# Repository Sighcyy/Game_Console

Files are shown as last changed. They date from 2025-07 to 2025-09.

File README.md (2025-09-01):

# Game_Console

This project is a custom-built, minimalist handheld game console inspired by the iconic Game Boy Color. Designed from the ground up, it features a compact PCB, a high-quality 3.5” LED display, and a rechargeable lithium-ion battery system—all housed in a sleek, ergonomically designed enclosure.

# Project Overview
Total Time Spent: ~18 hours

After completing two previous electronics projects focused primarily on PCB design and signal routing, I wanted to expand my skills by creating a fully portable device with a display and physical controls. The goal was to build a retro-style gaming device capable of running classic games like Pokémon, Tetris, and Super Mario while embracing a clean and minimalist aesthetic.

Key design decisions included using the Raspberry Pi Zero 2 WH as the main processing unit due to its compact size and emulation capabilities, and choosing an LED screen without integrated audio to simplify the design. The power system was upgraded to a rechargeable lithium-ion battery paired with a boost converter, allowing efficient voltage regulation and easy wiring underneath the Pi board.

Technical Highlights
Compact PCB Layout: Designed under 100x100 mm for cost-effective manufacturing and compactness.

Component Integration: Custom 3D CAD modeling to accommodate the battery, boost converter, microcontroller, and display, ensuring precise fit within a custom enclosure.

Minimalist Design: Removed unnecessary components such as the rotary encoder to maintain a streamlined, user-friendly form factor.

Firmware & Emulation: Leveraged RetroPie, a community-supported emulator platform that supports extensive button configuration, simplifying software setup.

Custom Soldering Documentation: Created unique schematic visualizations to document the process of soldering wires to the underside of the Raspberry Pi Zero 2 WH for a clean internal layout.



# Project Goal
The goal of this project is to create a fully functional, portable retro gaming console that captures the nostalgic feel of classic handheld devices like the Game Boy Color. This involves designing a compact, cost-effective PCB layout under 100x100 mm that integrates the Raspberry Pi Zero 2 WH, a 3.5” LED display, power components, and physical controls. A minimalist yet ergonomic enclosure is developed through precise 3D CAD modeling to securely house all parts while maintaining a sleek form factor. The project also aims to implement a reliable rechargeable power system using a lithium-ion battery and boost converter for consistent voltage delivery. By leveraging open-source emulation software like RetroPie, the console supports a wide range of classic games with easily configurable controls, simplifying the firmware side of the build. Finally, clear documentation of the hardware assembly, including custom wiring and soldering techniques, ensures the design is reproducible and ready for future enhancements.

# BOM


# CAD




# PCB and Shcematic and Wiring





# Firmware



https://retropie.org.uk/

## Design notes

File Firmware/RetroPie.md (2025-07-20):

For this section of the game console I have decided to use a pre-made OS called Retro Pie, which I can download into a MicroSD card and configured controls and insert ROM games in order to actually be able to play games. Below I have included the link to the time:

https://retropie.org.uk/

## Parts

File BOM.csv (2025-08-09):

Name | Vendor | Cost | Link
Touch Display | Waveshare | $24.99 | https://www.waveshare.com/product/raspberry-pi/3.5inch-rpi-lcd-c.htm
M3 Screw Assortment Kit | Ali-Express | $8.66 | https://www.aliexpress.us/item/3256803907721123.html?mp=1
HDMI Male to Female Flat Cable | Amazon | $7.59 | https://www.amazon.com/gp/product/B09F61FZWQ/ref=ox_sc_act_title_2?smid=A13KR3FLHKYL23&psc=1
2 pin Switches | Ali-Express | $1.15 | https://www.aliexpress.us/item/3256804784951471.html?mp=1
Heatsink | Ali-Express | $2.99 | https://www.aliexpress.us/item/3256807274777041.html?mp=1
On Off SWitch | Ali-Express | $4.59 | https://www.aliexpress.us/item/3256801856423528.html?mp=1
Raspberry Pi Zero W 2 with Headers | Micro Center | $17.99 | https://www.microcenter.com/product/683270/Raspberry_Pi_Zero_W_2_with_Headers
50 ft. 30AWG Silicone Cover Stranded-Core Wire | Micro Center | $4.99 | https://www.microcenter.com/product/471495/50_ft_30AWG_Silicone_Cover_Stranded-Core_Wire_-_Red
Lithium Ion Battery - 3.7v 2000mAh | Micro Center | $9.96 | https://www.microcenter.com/product/503621/Lithium_Ion_Battery_-_37v_2000mAh
MicroSD with Adapter | Micro Center | $4.99 | https://www.microcenter.com/product/658767/64GB_Ultra_microSDXC_Class_10_Flash_Memory_Card_with_Adapter
PowerBoost 1000 Charger | Micro Center | $19.99 | https://www.microcenter.com/product/474415/PowerBoost_1000_Charger_-_Rechargeable_5V_Lipo_USB_Boost_@_1A
Shipping Total | Waveshare | $15 | ________
Shipping Total | Amazon | $0 | ___________
Shipping and Additional Charges Total | Ali-Express | 11.89 | ____________-
Shipping Total | MicroCenter | $10 | __________
Total | All Places | $124.79 | ________-
Final Costs with Tax Estimation | All Places | $130 | ___

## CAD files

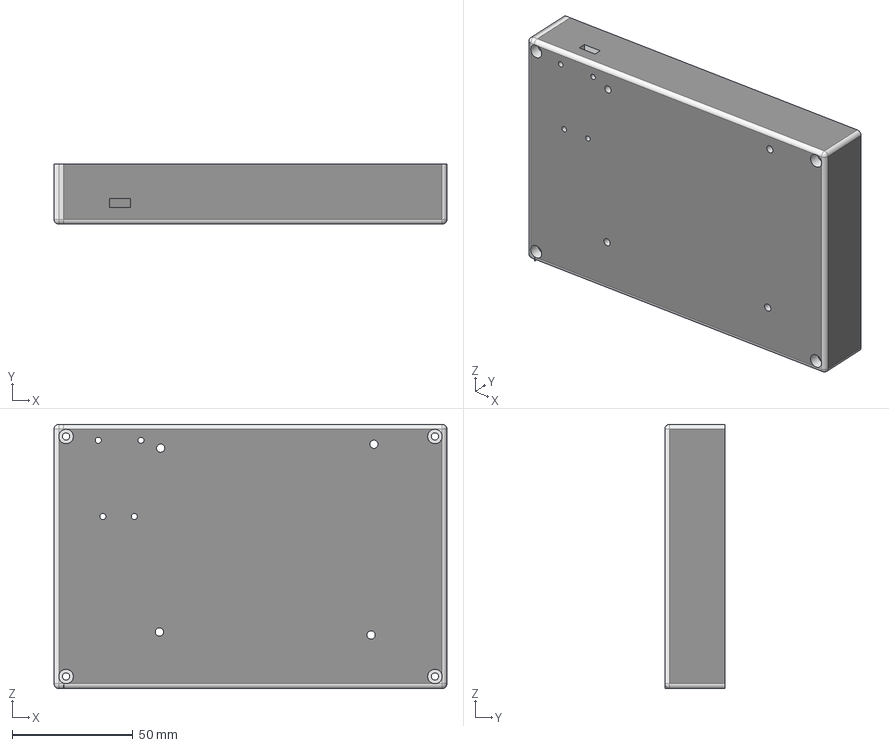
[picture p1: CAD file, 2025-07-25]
CAD/COC.stp
162.6 x 25.0 x 109.4 mm

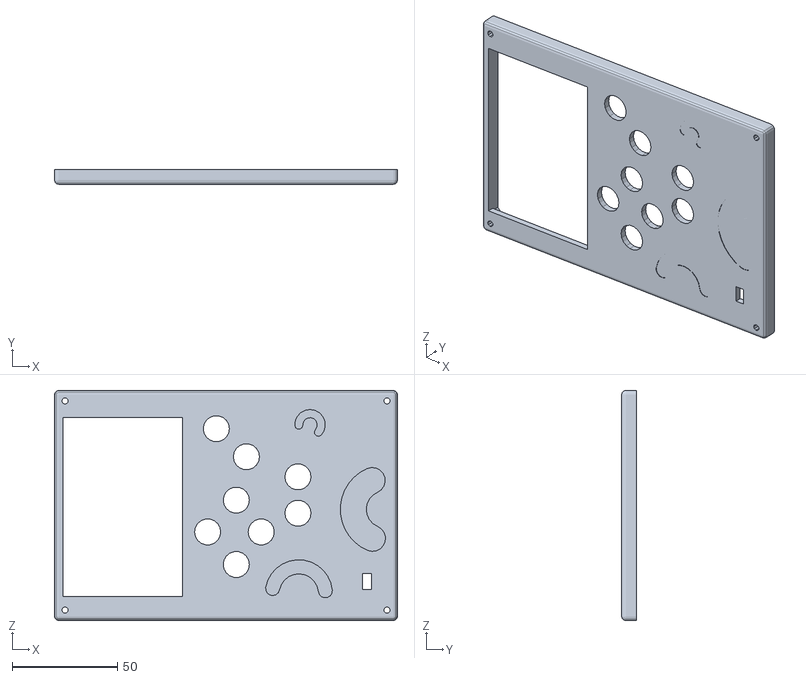
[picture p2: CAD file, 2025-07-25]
Production/POC.stl
162.9 x 7.00 x 109.3

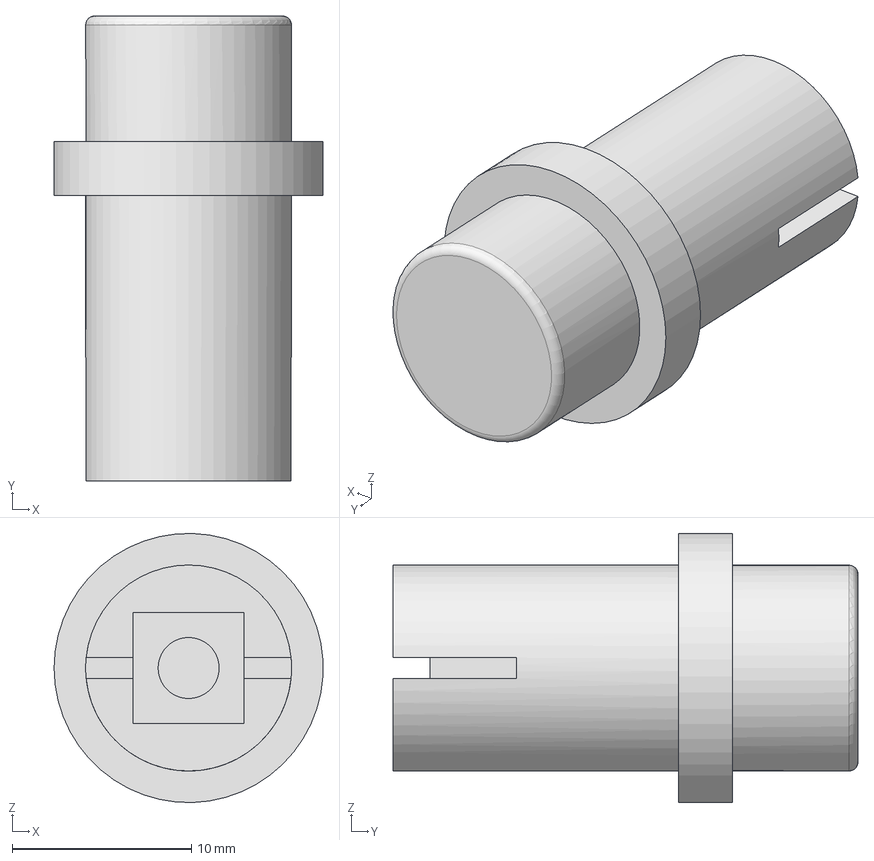
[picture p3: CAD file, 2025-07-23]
CAD/THEREALBUTTON.stp
15.0 x 25.9 x 15.0 mm

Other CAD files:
CAD/POC.stp
Production/COC.stl
Production/THEREALBUTTON.stl
CAD/COC.ipt
CAD/COC.stl
CAD/Fully_made_PCB.iam
CAD/POC.ipt
CAD/THEREALBUTTON.ipt

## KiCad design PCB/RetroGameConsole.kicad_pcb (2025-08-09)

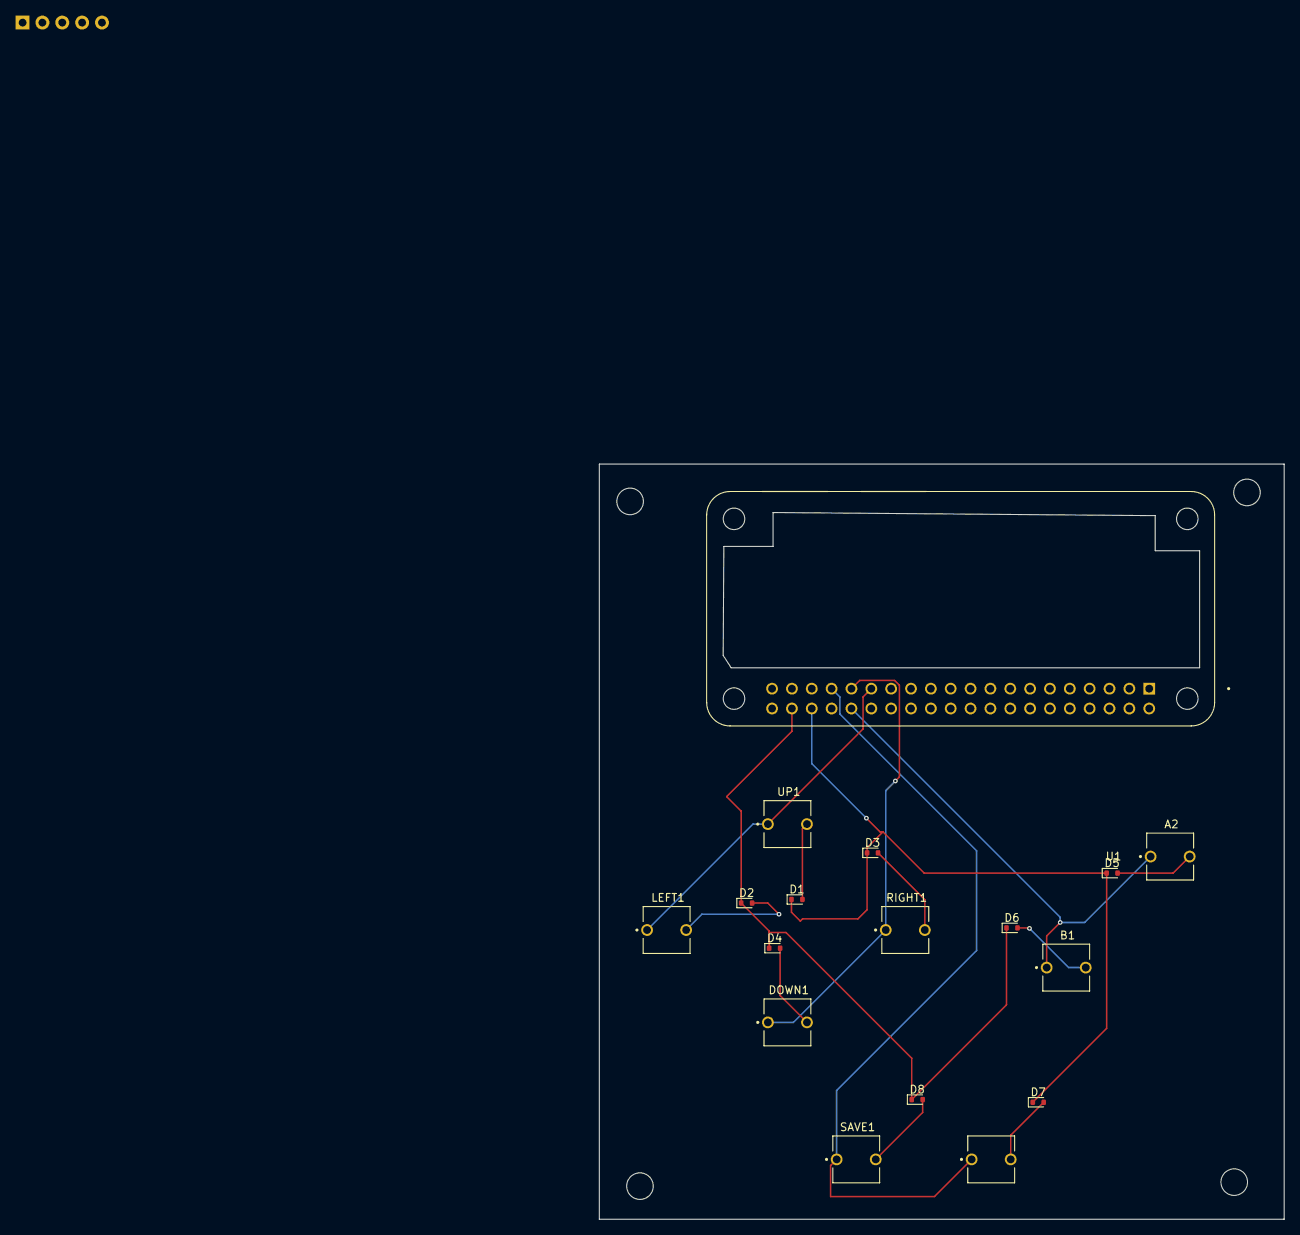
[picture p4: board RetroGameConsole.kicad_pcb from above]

Board: 2 copper layers, 87.6 x 96.6 mm, 18 parts (0 on the bottom side), 14 nets.

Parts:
A2: BUTT-2; SW_BUTT-2
B1: BUTT-2; SW_BUTT-2
D1, D2, D3, D4, D5, D6, D7, D8: 1N4148WT; D_SOD-523
DOWN1: BUTT-2; SW_BUTT-2
LEFT1: BUTT-2; SW_BUTT-2
RIGHT1: BUTT-2; SW_BUTT-2
SAVE1: BUTT-2; SW_BUTT-2
SELECT1: BUTT-2; SW_BUTT-2
U1: RASPBERRY_PI_ZERO_2_W; MODULE_RASPBERRY_PI_ZERO_2_W
U2: PAM8302AASCR; 1X05_ROUND_70
UP1: BUTT-2; SW_BUTT-2

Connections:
Column1: LEFT1.1, U1.29 (GPIO5), UP1.1
Column2: DOWN1.1, RIGHT1.1, U1.31 (GPIO6)
Column3: A2.1, B1.1, U1.32 (GPIO12)
Column4: SAVE1.1, SELECT1.1, U1.33 (GPIO13)
unnamed: D1.2 (A), UP1.2
unnamed: D2.2 (A), LEFT1.2
unnamed: D3.2 (A), RIGHT1.2
unnamed: D4.2 (A), DOWN1.2
unnamed: A2.2, D5.2 (A)
unnamed: B1.2, D6.2 (A)
unnamed: D7.2 (A), SELECT1.2
unnamed: D8.2 (A), SAVE1.2
Row1: D1.1 (K), D3.1 (K), D5.1 (K), D7.1 (K), U1.36 (GPIO16)
Row2: D2.1 (K), D4.1 (K), D6.1 (K), D8.1 (K), U1.38 (GPIO20)

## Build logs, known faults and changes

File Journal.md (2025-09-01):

# June 29th, 2025
Time: 2 hours

Today was a significant milestone in my personal electronics journey. After completing my second project—which was heavily focused on PCB design and signal routing—I realized there were areas I hadn’t explored yet, particularly portability, audio integration, and display hardware. With that in mind, I decided to begin my third project: designing and building a custom retro-style handheld game console. Inspired by the Game Boy Color and the nostalgia of games like Pokémon, Tetris, and Super Mario, I wanted to create something that captured that retro aesthetic but also pushed me into new technical territory. Unlike my previous work, this project would combine multiple disciplines: display interfacing, audio output, power management, and user input through physical controls.

Today’s focus was on planning and sourcing all the core components. I researched compact 3.5” displays compatible with SPI or parallel interfaces, small mono speakers with amplifier boards like the PAM8302, and a rechargeable Li-Po battery system using modules such as the PowerBoost 1000C. I also started considering how to route inputs from tactile buttons into the main processing board—likely a Raspberry Pi Zero 2 W for its compact form and emulation capabilities. With the parts identified, the next step is to begin the schematic design, where I’ll bring together power, video, audio, and controls into a single PCB. While I have ideas for future enhancements, like a unique case or custom OS interface, today was about laying the technical foundation.



# June 30th, 2025
Time : 3 hours

Today was all about refining the hardware planning process. I initially ran into a roadblock when I discovered that many of the footprints for the switches I intended to use were missing from the standard libraries. To solve this, I turned to SnapEDA to search for compatible footprints and cross-referenced them with GrabCAD to find accurate 3D models. This allowed me to visualize how each component would fit together, especially in relation to the microcontroller and 3.5” LED screen, helping me take precise measurements and maintain ergonomic spacing for the physical controls.

During this process, I made a key decision to switch my microcontroller to a Raspberry Pi Zero 2 WH. Its onboard Wi-Fi and processing power made it a better fit for a retro game console, especially for emulation tasks and future expandability. With most of the components selected and properly modeled, I sketched out a rough layout of the PCB, visualizing how everything—screen, buttons, speakers, power module—would come together on a single board. This early planning stage will help streamline the schematic and layout phase moving forward.

 


# July 1st, 2025
Time: 3 hours

Today didn’t go as smoothly as I had hoped. I set out to dive deeper into the functionality of the display, power supply, and audio system, hoping to clarify how everything would work together before moving forward with the schematic. While researching, I realized that ensuring a stable power supply from the battery pack would require a buck converter to regulate voltage efficiently. This added complexity made me realize that the project is more challenging than I initially expected. A lot of time was spent just finding component footprints, saving them, and organizing them for future use—something that seems simple but ended up being surprisingly time-consuming.

The most frustrating part of the day came when I thought I wouldn’t have enough available GPIO pins, since the LED screen alone was using 26. That caused a lot of confusion and delayed progress until I found a pinout reference table showing which pins were actually occupied and which ones were still free to use. Thankfully, it turns out I still have enough pins for my other components. While I didn’t make much progress on the CAD model or PCB layout today, I did collect and save screenshots and research links that I’ll refer back to during the build. Even though it was a tough day, it was still valuable in helping me understand the deeper integration challenges of this project.





# July 2nd, 2025
Time: 1.5 Hours

Today was fully dedicated to research and preparation. I focused on gathering accurate 3D models for all the components I plan to use, which will be essential for designing a properly fitting enclosure later on. Making the case look clean and functional requires precise dimensions, so having reliable CAD references was a top priority. This meant going through part datasheets, mechanical drawings, and online libraries like GrabCAD and SnapEDA to ensure the models were correct and matched the components I plan to purchase.

To stay organized, I created a dedicated folder containing all the part links—both for purchasing and downloading reference files—so everything is centralized when I begin the CAD design. This research phase may not be flashy, but it’s critical for avoiding mistakes later in the build. With the 3D models now in place, I’ll be able to begin roughing out the case design and start aligning it with my PCB layout in the next stages of the project.


# July 3rd, 2025
Time : 2 hours

Today marked the beginning of the CAD modeling phase, where I started shaping the physical form of my console and working toward a design that felt minimalist yet refined. One major decision I made was to exclude audio circuitry altogether. Instead, I opted for an LED screen that includes a built-in headphone jack, which simplifies the design and stays true to the clean aesthetic I’m aiming for. I want the final look to be simple and intentional on the outside, but technically impressive under the hood—something that reflects both elegance and complexity.

Another key update is that I determined a buck converter is no longer necessary, since my power supply already delivers the correct voltage required by the display. With that out of the way, I finalized my PCB design and officially transitioned into building the 3D model of the PCB. This step is critical, as it allows me to accurately position all components in CAD and begin shaping the custom case around them. From here, I’ll continue refining the layout and focus on making the enclosure both visually distinct and ergonomically sound.





# July 6th, 2025
Time : 0.5 hours

I was out with my family for the July 4th holiday and got back a bit later than expected, so I didn’t have as much time to work on the project today. That said, I still wanted to make some progress and began focusing on the next major step: designing the case for the handheld console.

I started working on the bottom layer of the enclosure, which will house the PCB, battery, and internal wiring. This part is crucial since it determines how the components will sit, how the case will be assembled, and how much internal clearance I’ll need. I kept the design simple for now, focusing mainly on layout and structural alignment, and I’ll refine it as I go.


# July 7th, 2025
Time: 2.5 hours

A lot changed today as I took a step back and evaluated my console by listing out its pros and cons. After reviewing the list, I realized I wasn’t satisfied with several key design choices—so I set out to fix them. The first major change was the power system. I decided to switch to a rechargeable lithium-ion battery paired with a boost converter, which not only simplified wiring but made it easier to integrate underneath the Raspberry Pi Zero 2. This setup offers more flexibility and fits better with the portable, self-contained design I’m aiming for.

I also wasn’t happy with the length of the PCB, so I resized the board to fit within 100x100mm—making it more compact and cheaper to manufacture. With the new dimensions in mind, I began rebuilding the case from scratch, and it’s already turning out much cleaner and better aligned. Another improvement involved removing the rotary encoder, which awkwardly stuck out from the case and didn’t contribute enough to justify the hassle. Looking ahead, I’ll need to update the schematic to reflect the new power setup and document how I plan to solder wires to the underside of the Pi. Tomorrow’s focus will be designing a dedicated compartment for the battery and boost converter to keep the internal layout organized and accessible.





# July 10th, 2025
Time: 1.5 Hours

I dedicated most of today to working on the CAD model of the console. A big focus was creating a dedicated compartment for the lithium-ion battery and boost converter, along with a precise cutout on the case for access and airflow. Integrating these components cleanly into the design required careful attention to spacing, alignment, and fit, especially to keep things compact without compromising functionality.

In addition to that, I spent a significant amount of time trying to minimize the overall size of the enclosure. Every millimeter mattered, so I went through multiple iterations, adjusting internal placements and wall thicknesses to shrink the footprint wherever possible. The result is a much more efficient and streamlined case design that better matches the compact 100x100 PCB layout I finalized earlier.



# July 11th, 2025
Time: 1.5 hours

Today was a big milestone—I officially finished the entire CAD model of the console. With the physical design complete, I shifted focus to what I expected to be the easier part: finding a community-supported emulator for running retro games. After a quick search, I came across RetroPie, which turned out to be exactly what I needed. It supports a wide range of classic consoles and even comes with built-in tools for button configuration, which made the firmware setup much simpler than I anticipated.

I also made progress on the schematic, especially now that my hardware layout is finalized. One challenge I faced was figuring out how to document my plan to solder wires to the underside of the Raspberry Pi Zero 2, since that’s not a standard configuration. To address this, I created a custom visual representation in the schematic to clearly show the solder points and wiring paths. This will help keep everything organized and easier to follow during the assembly phase.
Boost to Pi
